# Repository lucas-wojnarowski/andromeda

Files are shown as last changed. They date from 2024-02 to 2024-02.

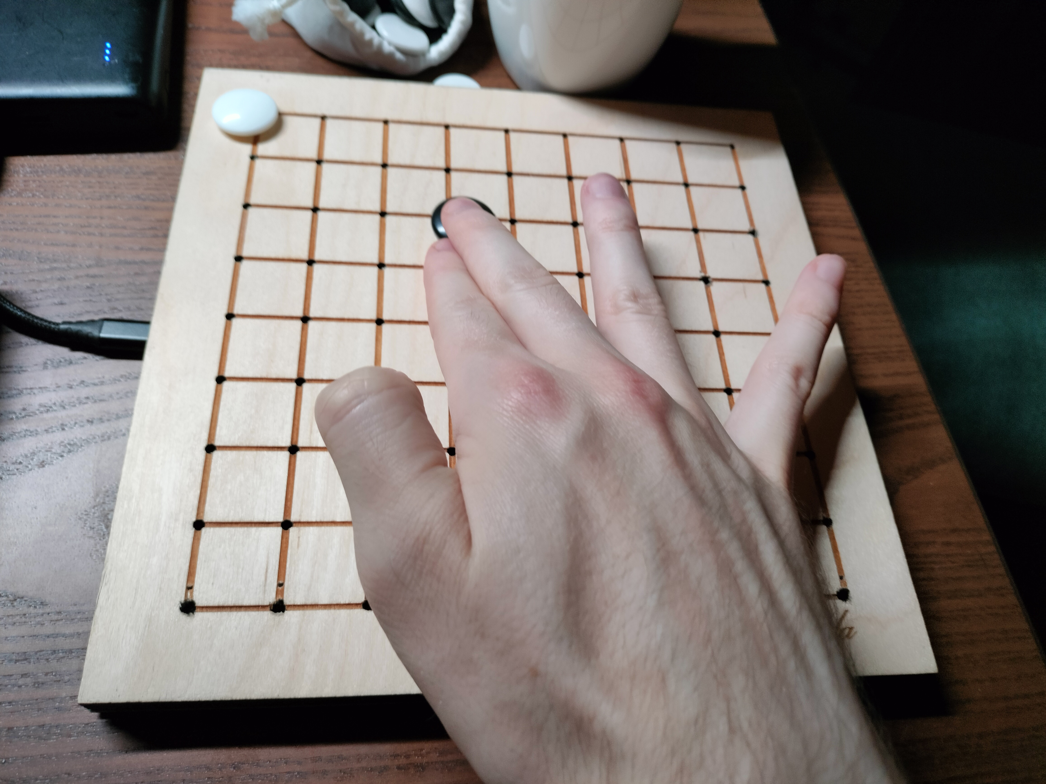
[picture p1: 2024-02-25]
Images/polozenie_kamienia.jpg

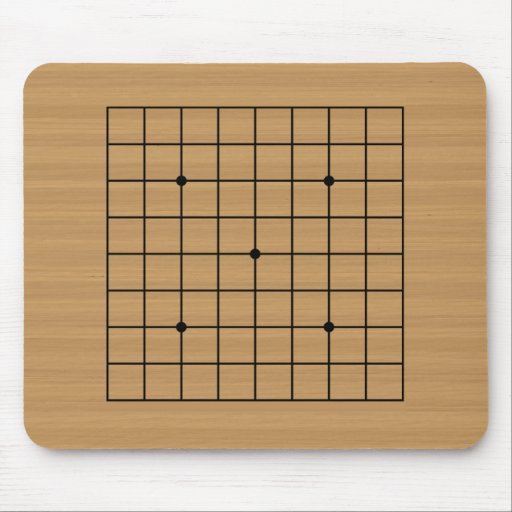
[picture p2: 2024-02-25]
9x9_board.png

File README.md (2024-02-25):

# andromeda
Automatic recognition of Go board state using electronic sensors

Presentation in polish language in Projekt Andromeda.pdf

To test this you need the hardware which currently is not available: I've made 1 piece only.

GUI.py - main application 

ML_Andromeda.ipynb - Google Colab notebook with sensor data analysis and training machine learning models

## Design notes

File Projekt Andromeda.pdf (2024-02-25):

# Projekt Andromeda

## Automatyczna detekcja kamieni na planszy Go

## Opis projektu

Projekt składa się z kilku części:

1) Elektroniczna plansza z sensorami na podczerwień oraz modułem Bluetooth:
2) Odbiornik Bluetooth przesyłający dane do portu COM
3) Aplikacja komputerowa wizualizująca dane z planszy
4) Analiza danych sensorycznych i trenowanie modeli ML w Google Colab

## Elektroniczna plansza

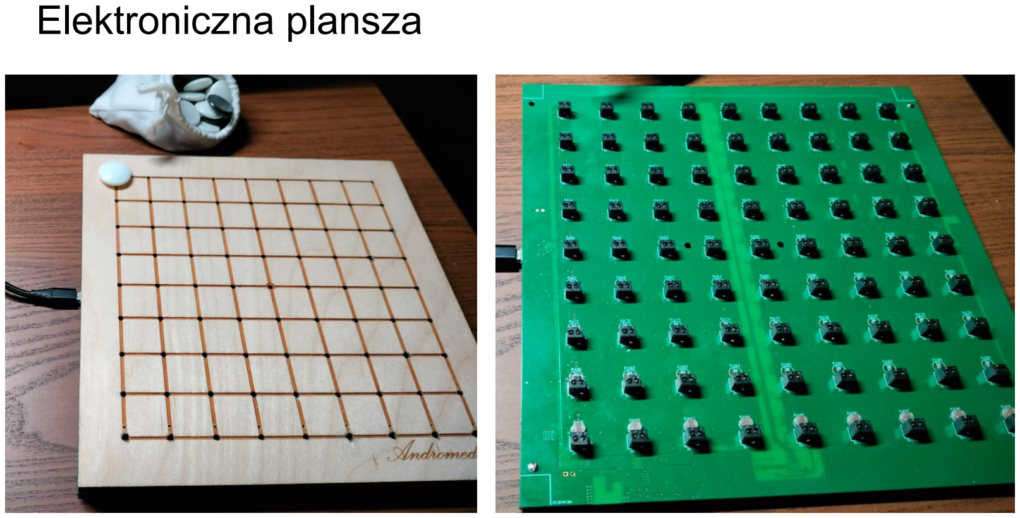
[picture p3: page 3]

## Elektroniczna plansza

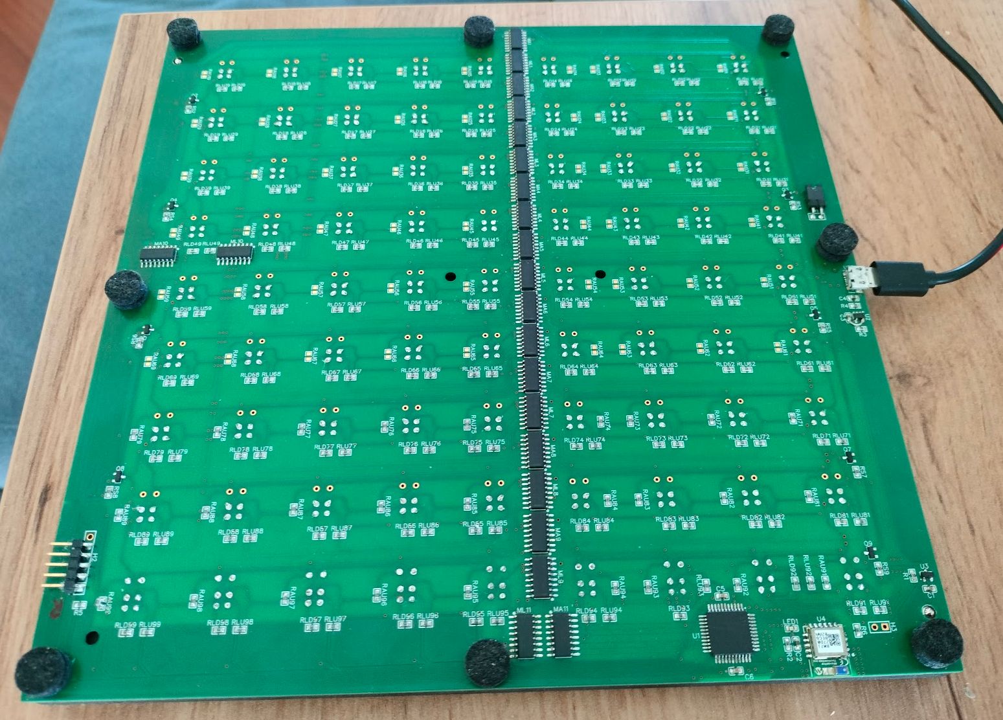
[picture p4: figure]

## Odbiornik Bluetooth - ESP32

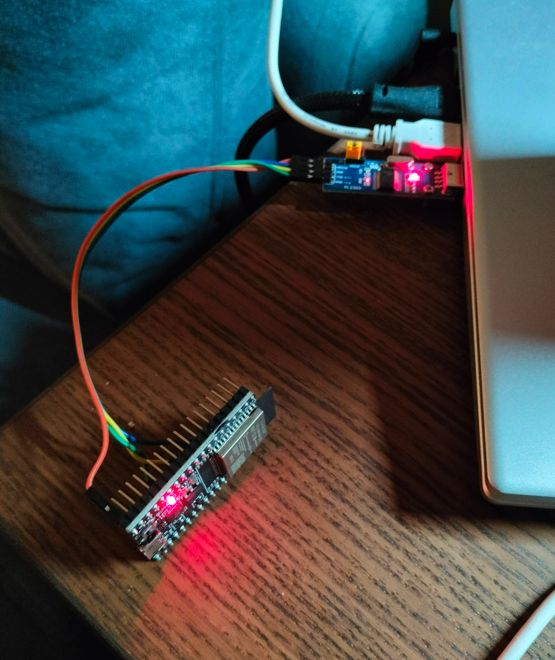
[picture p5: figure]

## Aplikacja komputerowa

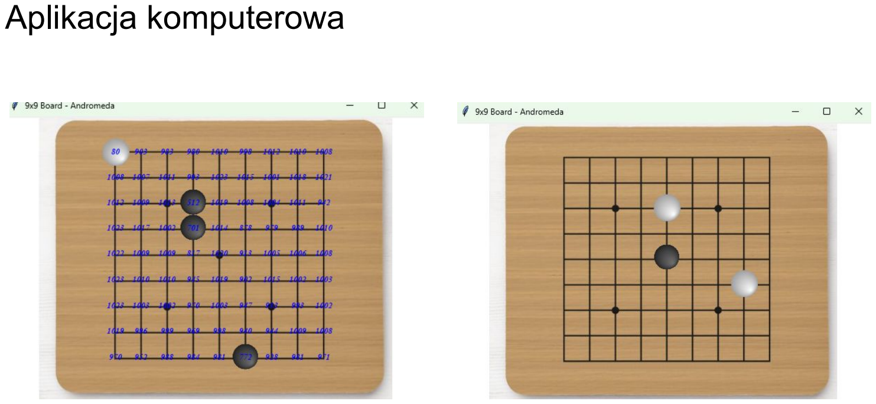
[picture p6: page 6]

## Dlaczego ML?

1) Model uczenia maszynowego służy głównie do automatyzacji procedury kalibracyjnej na podstawie pomiarów, można wyznaczyć metryki
2) Klasyczne modele są bardzo czasochłonne gdyż wymagają ręcznej kalibracji

## Analiza danych i trenowanie modeli

1) Model I - model regresji liniowej przetwarzający dane z sensorów na kolor w skali szarości
2) Model II - model klasyfikujący kolor w skali szarości do jednej z 3 grup: kamień biały, kamień czarny i brak kamienia

## Model I - regresja liniowa

1. W celu określenia koloru kamienia potrzebny jest model, który określi jego kolor w skali szarości

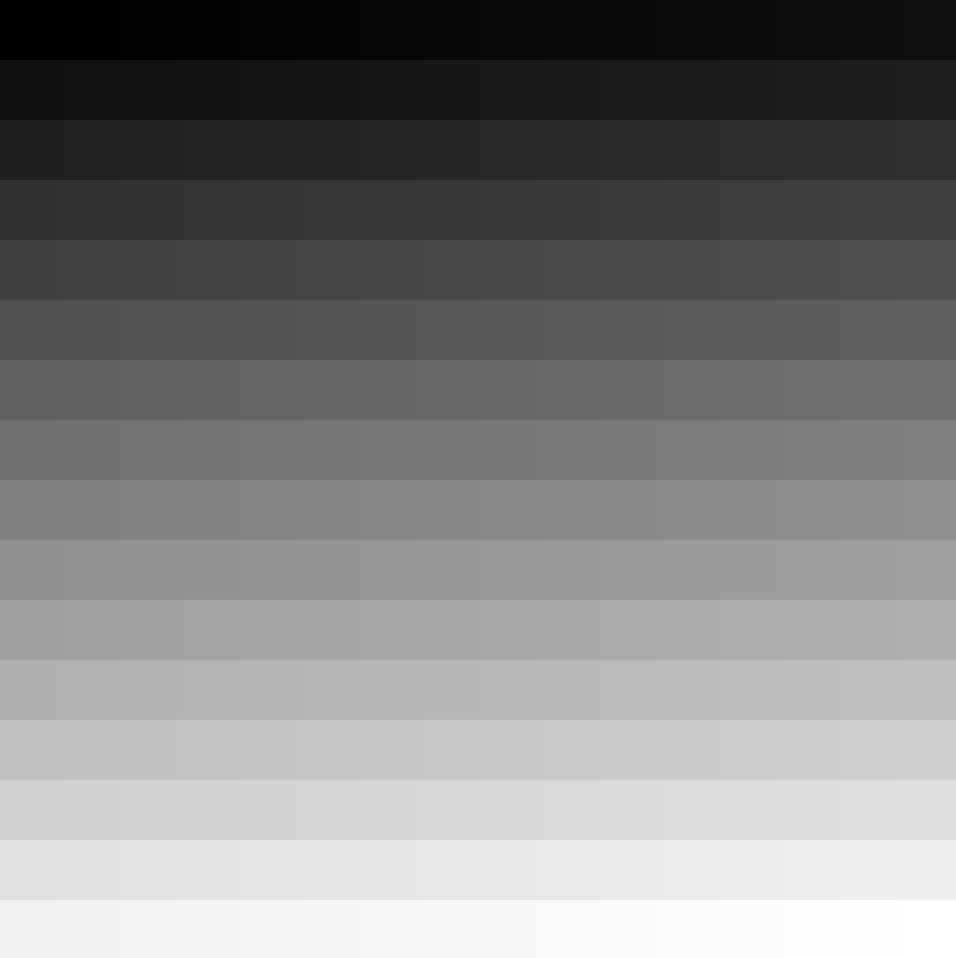
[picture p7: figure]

Dane wejściowe:

- odczyty z sensora nr 0 czytającego wydrukowany kolor od 0 do 130 - powyżej tej wartości sensor nie rozpoznaje

## Data cleaning

- Data cleaning ograniczył się tylko do usunięcia pomiarów które były nieprawidłowo wykonane

## Data visualization

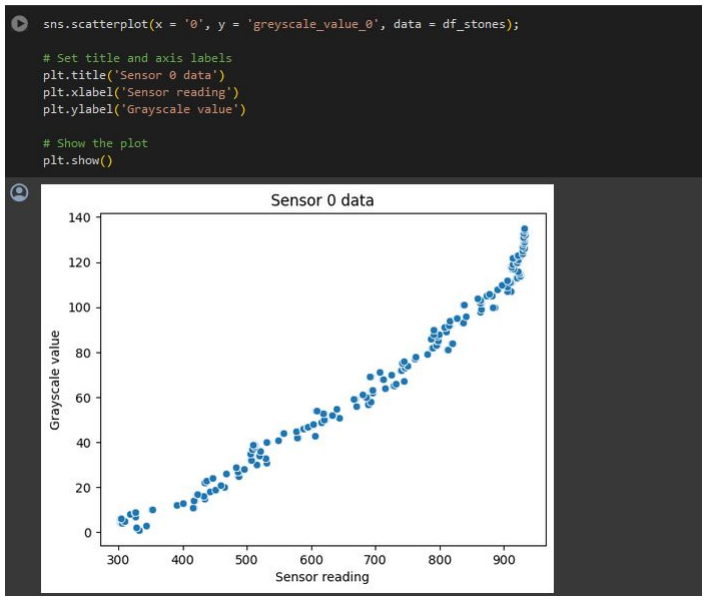
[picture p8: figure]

## Preparing data for training

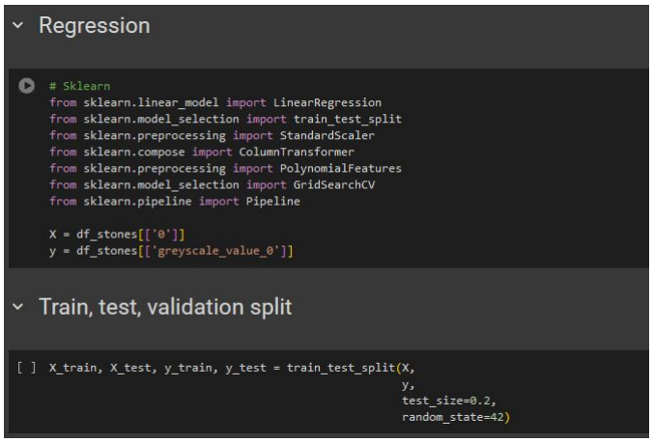
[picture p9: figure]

## Model training

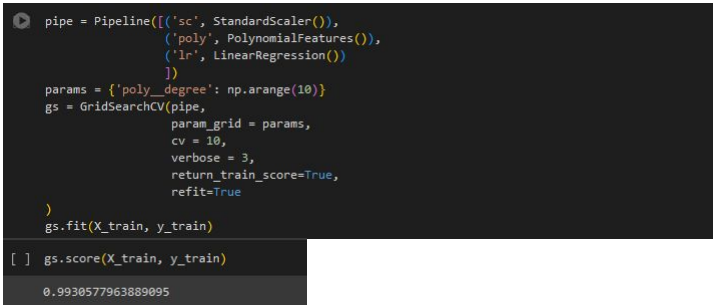
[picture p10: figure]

## Model validation

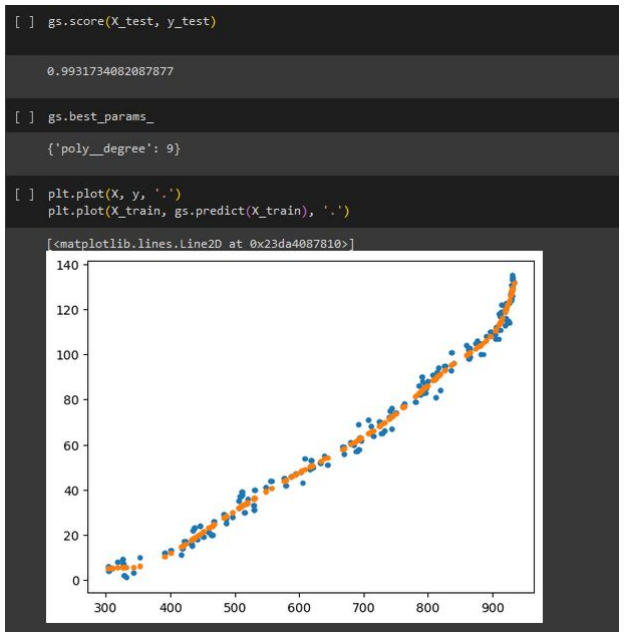
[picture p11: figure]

## Model export

## Model import on local machine

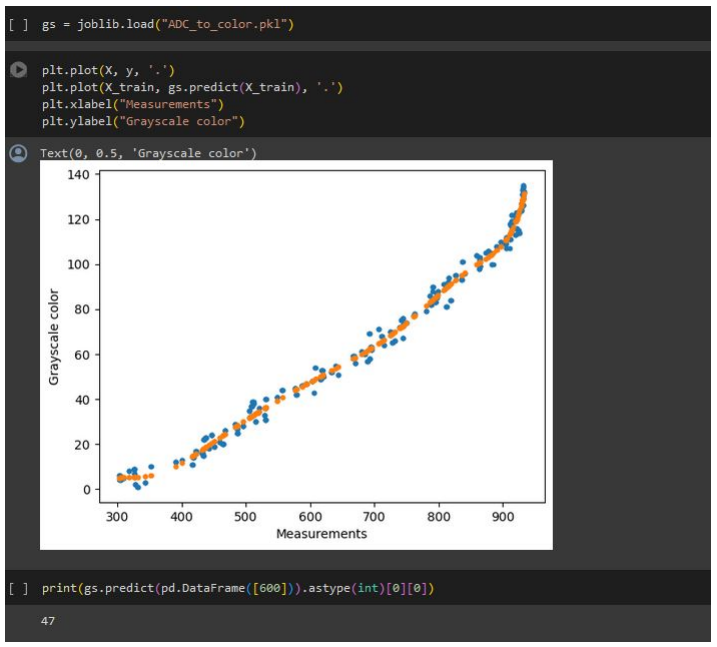
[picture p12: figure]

## Model II - klasyfikacja na podstawie koloru

1. Zebrano dane z 4 sensorów przykładając kamienie o różnej jakości, różnym kształcie i w różnym położeniu nad sensorem
2. Zbudowano model na podstawie danych z jednego sensora

## Import data

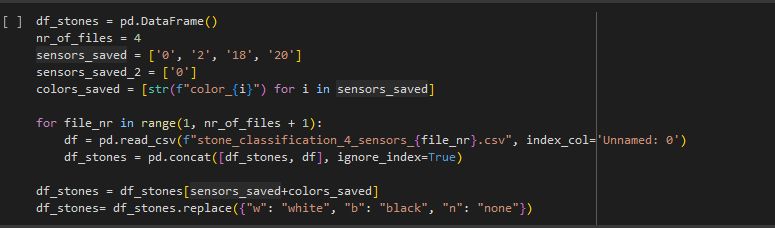
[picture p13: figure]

## Data cleaning

- Data cleaning polegał na odrzuceniu pomiarów, które zostały wykonane dla kamieni znajdujących się w dużej odległości od środka sensora

## Data exploration

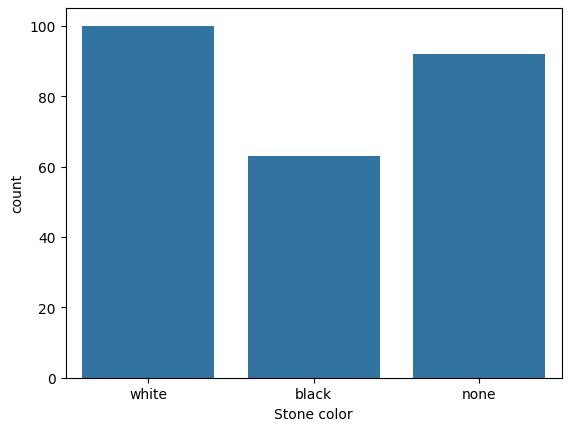
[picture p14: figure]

## Data exploration

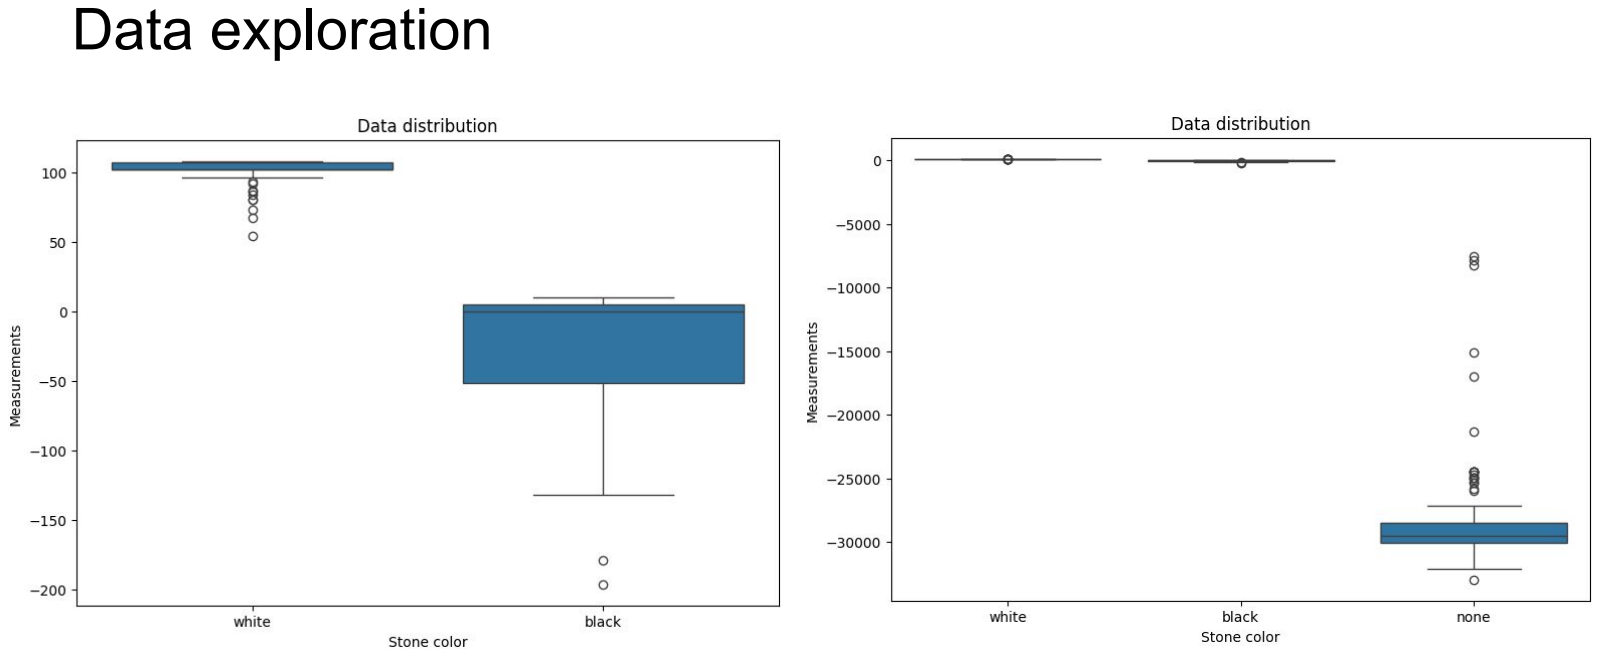
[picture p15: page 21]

## Preparing data for training

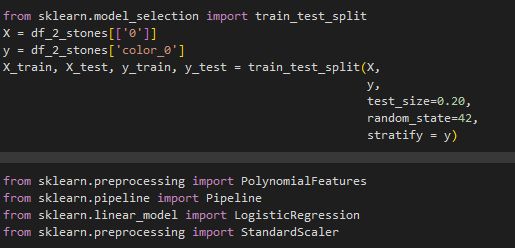
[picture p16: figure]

## Model training - logistic regression

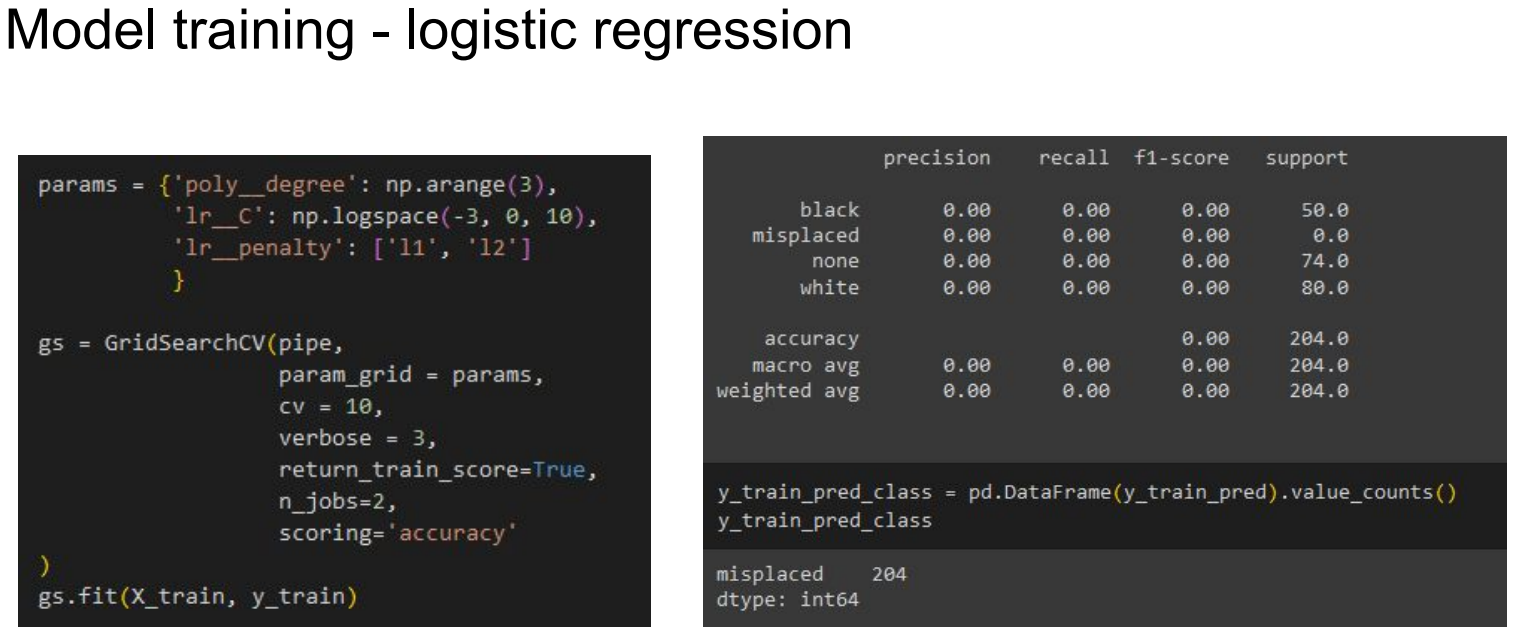
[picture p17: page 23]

## Model training - random forest

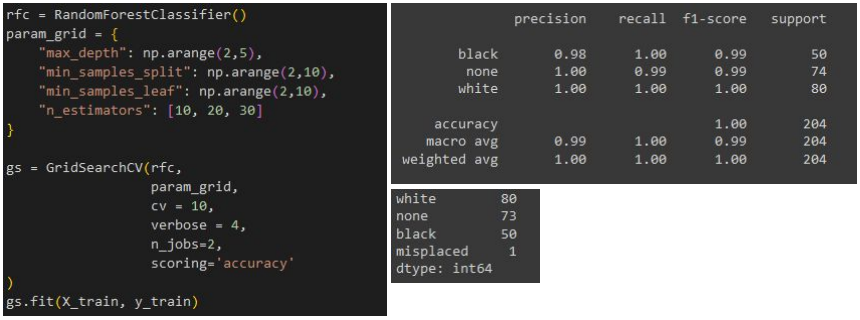
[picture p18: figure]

## Model test - random forest

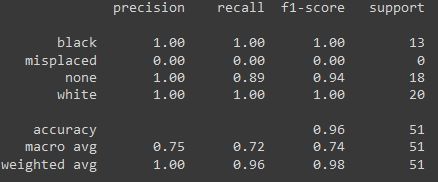
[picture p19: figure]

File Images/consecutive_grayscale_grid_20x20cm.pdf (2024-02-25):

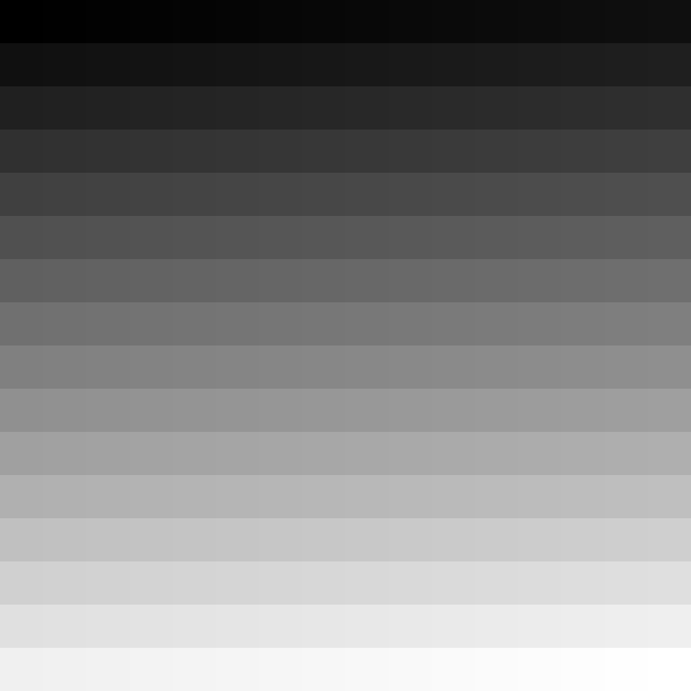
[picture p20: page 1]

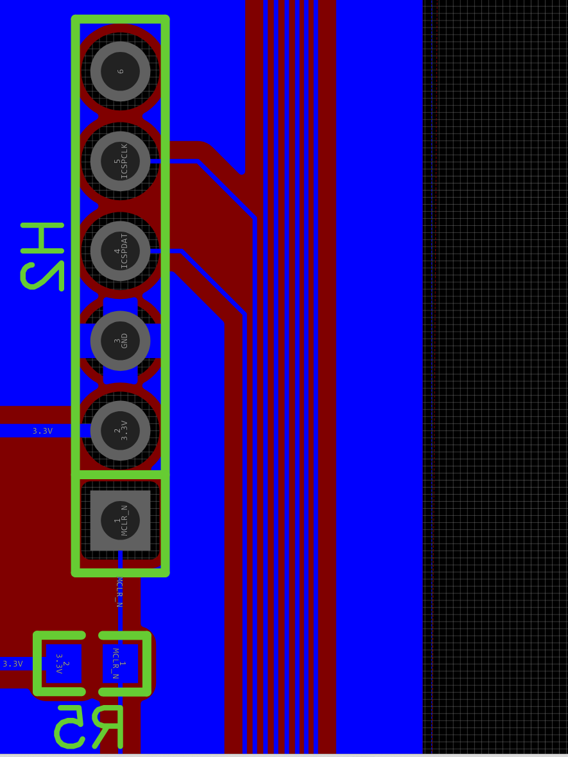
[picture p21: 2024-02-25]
Images/andromeda_pinout_prog.png

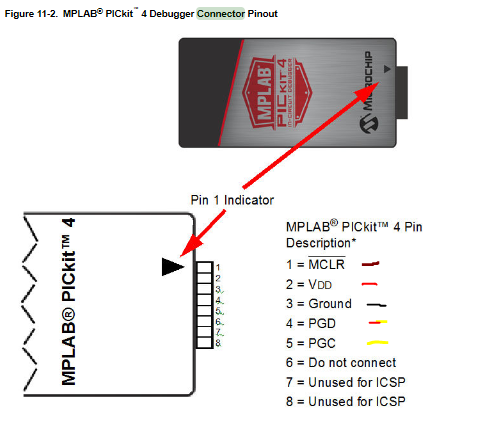
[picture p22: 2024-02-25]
Images/pickit4_pinout.PNG

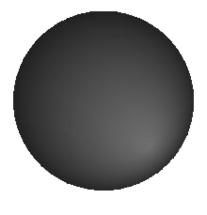
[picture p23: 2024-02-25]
black_stone.png

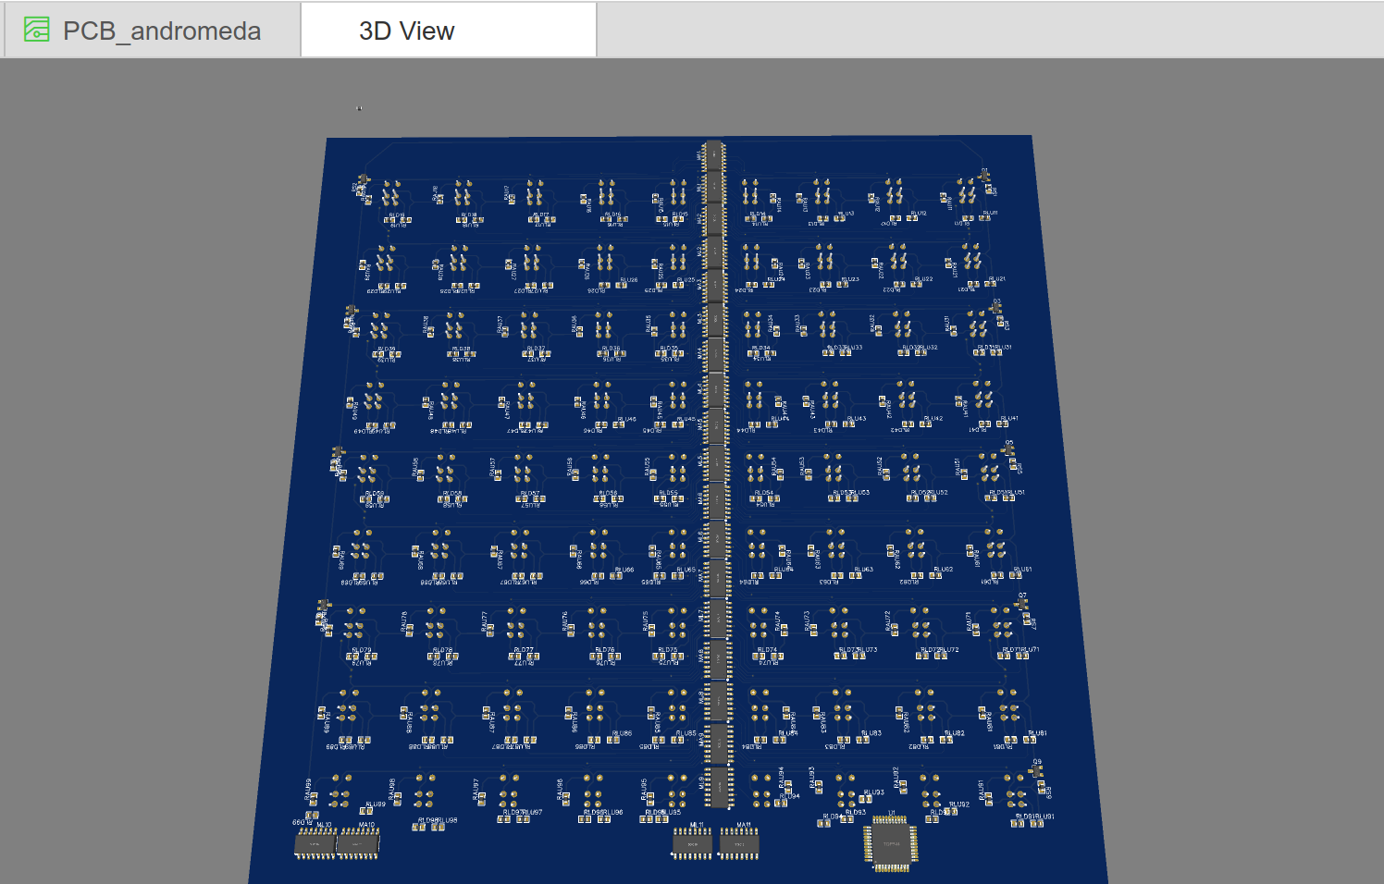
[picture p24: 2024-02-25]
Images/andromeda_3.png

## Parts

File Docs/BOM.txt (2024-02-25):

Płytka:
PCBWay: 2 layer, 319$ 10 pcs (120 PLN per board) , 440x440mm

PIC16F18877-I/PT - 1 szt. MOUSER - zamówione PIC16LF18877-I/PT z Microchip Direct, będzie 31.05
47346-0001 - 1 szt. FARNELL Z
LDLN030G33R - 1 szt. FARNELL Z
STM1061N19WX6F - 1 szt. FARNELL Z
BM71BLES1FC2-0B02AA lub BM71BLES1FC2-0B04AA - 1 szt. SAMPLE MICROCHIP - zamówione 3 szt. BM71BLES1FC2-0B02AA
YJL03G10A-F2-0000HF - 9 szt. - TME (warsztat)
SN74LV4051ADR - 22 szt. FARNELL Z
R 270 Ohm 0603 - 82 szt. Z
R 470k Ohm 0603 - 81 szt. Z
R 47k Ohm 0603 - 95 szt. Z
C 100n/6.3V 0603 - 2 szt. Z
C 1u/6.3V 0603 - 2 szt. Z
C 10u/10V 0603 - 2 szt. Z 
LED_0603 - 1 szt. warsztat
RPR-220 - 81 szt. Ali
GL5549 - 81 szt. Ali

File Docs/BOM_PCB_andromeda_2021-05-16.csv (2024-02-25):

ID | Name | Designator | Footprint | Quantity | Manufacturer Part | LCSC Part #（optional）
1 | 1u/6.3V | C1,C3 | 0603_C | 2 | C1608JB1C105KT000N | C694284
2 | 10u/10V | C2,C4 | 0603_C | 2
3 | 100n/6.3V | C5,C6 | 0603_C | 2
4 | PZ254V-11-06P | H2 | HDR-TH_6P-P2.54-V-M | 1 | PZ254V-11-06P | C492405
5 | HDR-F-2.54_1x2 | H1,H3 | HDR-F-2.54_1X2 | 2 |  | C49661
6 | LED-0603_R | LED1 | LED0603_RED | 1 | 19-217/R6C-AL1M2VY/3T | C72044
7 | SN74LV4051ADR | MA1,MA2,MA3,MA4,MA5,MA6,MA7,MA8,MA9,MA10,MA11,ML1,ML2,ML3,ML4,ML5,ML6,ML7,ML8,ML9,ML10,ML11 | SOIC-16_L10.8-W4.5-P1.27-LS6.8-BL | 22 | SN74LV4051ADR | C128414
8 | YJL03G10A-F2-0000HF | Q1,Q2,Q3,Q4,Q5,Q6,Q7,Q8,Q9 | SOT-23-3_L2.9-W1.3-P1.90-LS2.4-BR | 9 | YJL03G10A-F2-0000HF | C919604
9 | 47k | R1,R3,R4,R5,R6,RLU11,RLU12,RLU13,RLU14,RLU15,RLU16,RLU17,RLU18,RLU19,RLU21,RLU22,RLU23,RLU24,RLU25,RLU26,RLU27,RLU28,RLU29,RLU31,RLU32,RLU33,RLU34,RLU35,RLU36,RLU37,RLU38,RLU39,RLU41,RLU42,RLU43,RLU44,RLU45,RLU46,RLU47,RLU48,RLU49,RLU51,RLU52,RLU53,RLU54,RLU55,RLU56,RLU57,RLU58,RLU59,RLU61,RLU62,RLU63,RLU64,RLU65,RLU66,RLU67,RLU68,RLU69,RLU71,RLU72,RLU73,RLU74,RLU75,RLU76,RLU77,RLU78,RLU79,RLU81,RLU82,RLU83,RLU84,RLU85,RLU86,RLU87,RLU88,RLU89,RLU91,RLU92,RLU93,RLU94,RLU95,RLU96,RLU97,RLU98,RLU99,RS1,RS2,RS3,RS4,RS5,RS6,RS7,RS8,RS9 | R0603 | 95
10 | 270 | R2,RLD11,RLD12,RLD13,RLD14,RLD15,RLD16,RLD17,RLD18,RLD19,RLD21,RLD22,RLD23,RLD24,RLD25,RLD26,RLD27,RLD28,RLD29,RLD31,RLD32,RLD33,RLD34,RLD35,RLD36,RLD37,RLD38,RLD39,RLD41,RLD42,RLD43,RLD44,RLD45,RLD46,RLD47,RLD48,RLD49,RLD51,RLD52,RLD53,RLD54,RLD55,RLD56,RLD57,RLD58,RLD59,RLD61,RLD62,RLD63,RLD64,RLD65,RLD66,RLD67,RLD68,RLD69,RLD71,RLD72,RLD73,RLD74,RLD75,RLD76,RLD77,RLD78,RLD79,RLD81,RLD82,RLD83,RLD84,RLD85,RLD86,RLD87,RLD88,RLD89,RLD91,RLD92,RLD93,RLD94,RLD95,RLD96,RLD97,RLD98,RLD99 | R0603 | 82
11 | GL5549 | RA11,RA12,RA13,RA14,RA15,RA16,RA17,RA18,RA19,RA21,RA22,RA23,RA24,RA25,RA26,RA27,RA28,RA29,RA31,RA32,RA33,RA34,RA35,RA36,RA37,RA38,RA39,RA41,RA42,RA43,RA44,RA45,RA46,RA47,RA48,RA49,RA51,RA52,RA53,RA54,RA55,RA56,RA57,RA58,RA59,RA61,RA62,RA63,RA64,RA65,RA66,RA67,RA68,RA69,RA71,RA72,RA73,RA74,RA75,RA76,RA77,RA78,RA79,RA81,RA82,RA83,RA84,RA85,RA86,RA87,RA88,RA89,RA91,RA92,RA93,RA94,RA95,RA96,RA97,RA98,RA99 | RES-TH_L5.1-W4.3-P3.40-D0.5 | 81 | GL5549 | C125631
12 | 470k | RAU11,RAU12,RAU13,RAU14,RAU15,RAU16,RAU17,RAU18,RAU19,RAU21,RAU22,RAU23,RAU24,RAU25,RAU26,RAU27,RAU28,RAU29,RAU31,RAU32,RAU33,RAU34,RAU35,RAU36,RAU37,RAU38,RAU39,RAU41,RAU42,RAU43,RAU44,RAU45,RAU46,RAU47,RAU48,RAU49,RAU51,RAU52,RAU53,RAU54,RAU55,RAU56,RAU57,RAU58,RAU59,RAU61,RAU62,RAU63,RAU64,RAU65,RAU66,RAU67,RAU68,RAU69,RAU71,RAU72,RAU73,RAU74,RAU75,RAU76,RAU77,RAU78,RAU79,RAU81,RAU82,RAU83,RAU84,RAU85,RAU86,RAU87,RAU88,RAU89,RAU91,RAU92,RAU93,RAU94,RAU95,RAU96,RAU97,RAU98,RAU99 | R0603 | 81
13 | RPR-220 | RPR11,RPR12,RPR13,RPR14,RPR15,RPR16,RPR17,RPR18,RPR19,RPR21,RPR22,RPR23,RPR24,RPR25,RPR26,RPR27,RPR28,RPR29,RPR31,RPR32,RPR33,RPR34,RPR35,RPR36,RPR37,RPR38,RPR39,RPR41,RPR42,RPR43,RPR44,RPR45,RPR46,RPR47,RPR48,RPR49,RPR51,RPR52,RPR53,RPR54,RPR55,RPR56,RPR57,RPR58,RPR59,RPR61,RPR62,RPR63,RPR64,RPR65,RPR66,RPR67,RPR68,RPR69,RPR71,RPR72,RPR73,RPR74,RPR75,RPR76,RPR77,RPR78,RPR79,RPR81,RPR82,RPR83,RPR84,RPR85,RPR86,RPR87,RPR88,RPR89,RPR91,RPR92,RPR93,RPR94,RPR95,RPR96,RPR97,RPR98,RPR99 | LED-TH_4P_RPR-220 | 81 | RPR-220 | C21062
14 | PIC16F18877-I/PT | U1 | TQFP-44_L10.0-W10.0-P0.80-LS12.0-BL | 1 | PIC16F18877-I/PT | C81835
15 | LDLN030G33R | U2 | LDLN030G33R | 1 | LDLN030G33R | LDLN030G33R
16 | STM1061N19WX6F | U3 | STM1061N19WX6F | 1 | STM1061N19WX6F | STM1061N19WX6F
17 | BM71BLES1FC2-0B04AA | U4 | BM71BLES1FC2 | 1 | BM71BLES1FC2-0B04AA | BM71BLES1FC2-0B04AA
18 | 47346-0001 | USB1 | MICRO-USB-SMD_47346-0001 | 1 | 47346-0001 | C132560

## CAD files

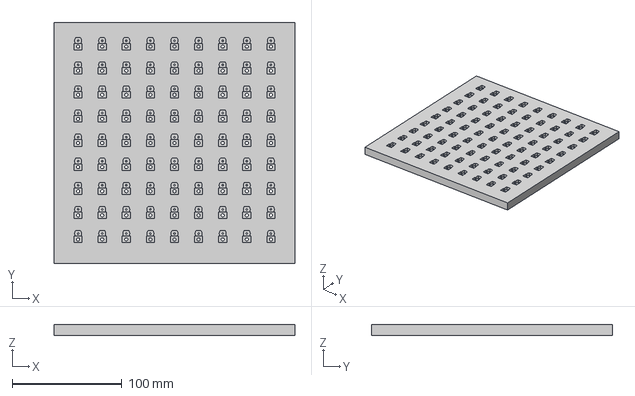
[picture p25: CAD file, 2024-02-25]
Images/andromeda.step
220.0 x 220.0 x 10.0 mm

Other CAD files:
Images/andromeda_v1.1.step
Images/andromeda.ipt

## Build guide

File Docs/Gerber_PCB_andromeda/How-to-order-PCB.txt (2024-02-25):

How to Order PCB

Please refer to:
https://docs.easyeda.com/en/PCB/Order-PCB

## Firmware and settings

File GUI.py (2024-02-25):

import sys
from tkinter import *
from PIL import ImageTk, Image
import serial
from threading import Thread
import threading
import struct
import pandas as pd
import joblib
import numpy as np
import traceback
import os
import time

global df, df_adc, df_baseline
global key
global greyscale_grid_color
global color, previous_colors, baseline_calibration_done, previous_raw, display_debounce_counter, previous_delta

images_tags_list = [''] * 81
images_references_list = [''] * 81
images_text_reference_list = [''] * 81
FirstStoneX = 157
FirstStoneY = 50
PixelIncrementX = 37
PixelIncrementY = 36
PixelOffsetY = [0, 0, 0, 0, 0, 1, 2, 2, 3]
PixelOffsetX = [1, 0, 0, 0, 0, 0, 0, 0, 0]

port = serial.Serial('COM7', baudrate=117650, timeout=3.0)
root = Tk()
root.title("9x9 Board - Andromeda")
root.geometry("+100+50")

frame = Frame(root)
frame.pack()

canvas = Canvas(frame, width=600, height=400, bg="white")
canvas.pack()

board = Image.open("9x9_board.png").convert("RGBA").crop([0, 55, 500, 500])
background_img = ImageTk.PhotoImage(board)

display_debounce_counter = list(np.zeros(81))
previous_delta = list(np.zeros(81))
previous_raw = list(np.zeros(81))
previous_stones = ["none" for x in range(81)]
previous_colors = list(np.zeros(81))

canvas.create_image(300, 220, image=background_img)

df = pd.DataFrame()
df_adc = pd.DataFrame()
df_baseline = pd.DataFrame()
df_readings = pd.DataFrame()
label_colors = ["n" for x in range(81)]
baseline_calibration_done = False

key = ''
greyscale_grid_color = 0

gs = joblib.load("ADC_to_color.pkl")
gs_2 = joblib.load("color_to_class.pkl")

exit_flag = threading.Event()


def key_input():
    global key
    global greyscale_grid_color

    while not exit_flag.is_set():
        try:
            if key != 's':
                print(f"Measurement nr: {greyscale_grid_color}")
                key = input("Press s to start: ")
            elif key != 'C':
                key = input("Press d to stop: ")
                greyscale_grid_color = greyscale_grid_color + 1
            else:
                raise KeyboardInterrupt
        except KeyboardInterrupt:
            # Handle the KeyboardInterrupt (Ctrl+C) here
            print("Program was interrupted.")
        finally:
            pass
            # Optionally, perform any cleanup here
            # print("Exiting the program.")


def create_stone(file, x, y):
    images_references_list[9 * x + y] = PhotoImage(file=file).subsample(5, 5)
    images_tags_list[9 * x + y] = \
        canvas.create_image(FirstStoneX + PixelIncrementX * y + PixelOffsetX[y],
                            FirstStoneY + PixelIncrementY * x + PixelOffsetY[x],
                            image=images_references_list[9 * x + y])


def remove_stone(x, y):
    canvas.delete(images_tags_list[9 * x + y])
    images_tags_list[9 * x + y] = ''
    images_references_list[9 * x + y] = ''


def convert_uint16_to_int(byte_pair):
    return int.from_bytes(byte_pair, byteorder='big')


def serial_read():
    global df, df_adc, df_baseline, df_readings
    global key
    global greyscale_grid_color
    global color
    global previous_colors, baseline_calibration_done, display_debounce_counter, previous_delta, previous_raw

    while not exit_flag.is_set():
        header = False
        try:
            byte = convert_uint16_to_int(port.read(1))
            if byte == 1:
                byte = convert_uint16_to_int(port.read(1))
                if byte == 0:
                    byte = convert_uint16_to_int(port.read(1))
                    if byte == 162:
                        header = True
                        rcv_adc = port.read(162)
            if header:
                try:
                    adc_int = list(struct.unpack('>81H', rcv_adc))
                    if key == 's':
                        columns = [str(i) for i in range(81)] + [str(f"color_{i}") for i in range(81)]
                        # columns.append('greyscale_value')
                        # data = (df_baseline - df.tail(6).median()).tolist()
                        data = previous_colors + label_colors
                        df_adc_sample = pd.DataFrame([data], columns=columns)
                        df_readings = pd.concat([df_readings, df_adc_sample], ignore_index=True)
                        key = 'd'
                except Exception as e:
                    return

                columns = [str(i) for i in range(81)]
                df_adc = pd.DataFrame([adc_int], columns=columns)
                df = pd.concat([df, df_adc], ignore_index=True)

                for x in range(9):
                    for y in range(9):
                        canvas.delete(images_text_reference_list[9 * x + y])
                        if baseline_calibration_done:
                            delta = df_baseline.iloc[9 * x + y] - df.tail(filter_value)[f"{9 * x + y}"].median()
                            if ((np.abs(delta - previous_delta[9 * x + y]) < 10) &
                                    (display_debounce_counter[9 * x + y] < display_debounce_counter_value)):
                                display_debounce_counter[9 * x + y] += 1
                                color = gs.predict(pd.DataFrame({'0': [delta]})).astype(int)[0][0]
                                stone_class = gs_2.predict(pd.DataFrame({'0': [color]}))
                                if stone_class == 'white' and previous_stones[9 * x + y] != 'white':
                                    create_stone("white_stone.png", x, y)
                                    # print(f"Added white stone at {x}, {y} with color {color}")
                                elif stone_class == 'black' and previous_stones[9 * x + y] != 'black':
                                    create_stone("black_stone.png", x, y)
                                    # print(f"Added black stone at {x}, {y} with color {color}")
                                elif stone_class == 'none' and images_tags_list[9 * x + y] != '':
                                    # print(f"Removed at {x}, {y} with color {color}")
                                    remove_stone(x, y)
                                previous_stones[9 * x + y] = stone_class
                                previous_colors[9 * x + y] = color
                            elif np.abs(delta - previous_delta[9 * x + y]) > 10:
                                display_debounce_counter[9 * x + y] = 0

                            previous_raw[9 * x + y] = adc_int[9 * x + y]
                            previous_delta[9 * x + y] = delta
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
